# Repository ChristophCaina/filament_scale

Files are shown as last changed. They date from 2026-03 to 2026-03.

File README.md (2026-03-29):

# ⚖ ESPHome Filament Spool Scale & Winder

> 🇩🇪 [Deutsche Version weiter unten](#-esphome-filament-waage---wickler)

---

This project is an intelligent filament scale based on an ESP32. It offers precise weight measurement for 3D printing spools, an integrated spool database, and control for an optional winder add-on.  
The Primary goal of this project was also, to re-use some Hardware of an old Ender3 Printer, which is no longer in use.  
If you don't have the required parts remaining, consider to buy some cheap replacement parts online.

## ✨ Features

* **Precise Measurement:** Integration of a load cell (via `hx711` package) for real-time weight monitoring.
* **Smart UI:** Menu-driven display (via `st7920` package) with pagination.
<!-- * **Winder Mode:** Automatic detection of a stepper add-on for filament winding or unloading. -->
<!-- * **Potentiometer Control:** Stepless speed control of the stepper motor via analog potentiometer. -->
* **Modular Design:** Thanks to ESPHome "Packages," the logic is strictly separated from the hardware configuration.
* **Spoolman Integration:** Automatic sync of spool weight and status with your [Spoolman](https://github.com/Donkie/Spoolman) instance.
* **FilaMan Integration:** Compatible with [FilaMan](https://docu.filaman.app/) — a web-based open-source filament management system. Measured spool weights can be pushed to FilaMan for inventory tracking, fill-level monitoring, and printer integration (OctoPrint, Klipper/Moonraker).

---

## 🛠 Hardware & Pinout

Configuration is handled via `substitutions` in the local YAML file. The following pins are assigned by default:

| Component | Pin | Description |
| :--- | :--- | :--- |
| **Status LED** | GPIO02 | System status indicator |
| **Display (SPI)** | GPIO18 (CLK), GPIO23 (MOSI), GPIO17 (CS) | ST7920 128x64 LCD (`st7920` package) |
| **Rotary Encoder** | GPIO32 (A), GPIO33 (B), GPIO19 (BTN) | Navigation & Selection |
| **Buzzer** | GPIO16 | Acoustic feedback |
| **Load Cell (Scale)** | GPIO21 (DT), GPIO22 (SCK) | HX711 interface (`hx711` package) |
| **I2C Interface** | GPIO13 (SDA), GPIO14 (SCL) | Extensions(*) |
<!-- | **Stepper Motor** | GPIO25 (STEP), GPIO26 (DIR) | Winder drive | -->
<!-- | **Filament Sensor** | GPIO27 | Runout detection |-->
<!-- | **Speed** | GPIO34 (Analog) | Potentiometer (0 – 3.3V) | -->
<!-- | **Add-on Detection** | GPIO05 (Inp. Pullup) | Detects plugged-in winder module | -->

> **Note:** It is planned to add some extensions as an optional addon to this scale in the future, like a Spool-Rewinder and addon-detection. These will be added and documented once the hardware-design is finalized
---

## 🚀 Installation & Setup
this section isn't ready yet and will be adjusted over time.

<!-- To use this project on your hardware, follow these steps:

1. Create a **new device** in your ESPHome dashboard.
2. Copy the content of the [example_config.yaml](example_config.yaml) file from this repository.
3. Replace the content of your local configuration in the ESPHome dashboard with the copied text.
4. **Customization:**
   * Enter your WiFi credentials (`ssid` & `password`).
   * API and OTA keys are usually generated automatically by ESPHome when creating the device – ensure these are kept or regenerated.
   * Check the `substitutions` section to ensure the pinout matches your hardware.
5. **Compile & Install:** Click "Install" (USB or OTA).
6. **First Start:** After booting, zero the scale once via the menu item `1. Tare`.

### Spoolman Configuration

To configure Spoolman, set the substitution in the `example_config.yaml` to your Spoolman instance:

```yaml
spoolman_ip: "192.168.0.1:7912"
```

### FilaMan Configuration

[FilaMan](https://docu.filaman.app/) is a web-based open-source application for managing your filament inventory. It supports fill-level monitoring, manufacturer & filament tracking, storage locations, and printer integrations (OctoPrint, Klipper/Moonraker).

To connect this scale to FilaMan, set the corresponding substitution in the `example_config.yaml`:

```yaml
filaman_ip: "192.168.0.1:8083"
```

FilaMan can also be run as a **Home Assistant Add-on** — see [ha-filaman-system](https://github.com/netscout2001/ha-filaman-system).
-->

## Documentation:
* [Concept](docs/concept.md)
* [Hardware](docs/hardware.md)
* [Calibration](docs/calibration.md)
* [API Documentation](docs/api.md)

<!--
---
## 🌱 Supported Filament Suppliers

### Recycling Fabrik
Recycled filament from collected 3D printing waste.
Compatible with FilaMan NFC tags (coming soon).

<!-- [Shop ↗](https://recyclingfabrik.com) | [Collab Program ↗](https://recyclingfabrik.com/pages/collab)

> ℹ️ Affiliate links help support this project at no extra cost to you.
-->
---
 
## 📄 License
 
This project uses different licenses for different components:
 
| Component | License |
| :--- | :--- |
| **Firmware & Software** (YAML, Scripts, Workflows) | [MIT License](LICENSE) |
| **Hardware** (3D Print Files, PCB Layouts, Schematics) | [CC BY-NC-SA 4.0](LICENSE-HARDWARE) |
| **Documentation** | [CC BY-SA 4.0](https://creativecommons.org/licenses/by-sa/4.0/) |
 
### MIT License (Software)
The firmware and all software components are free to use, modify and distribute — including for commercial purposes — as long as the copyright notice is retained.
 
### CC BY-NC-SA 4.0 (Hardware)
Hardware design files (3D prints, PCB layouts) may be freely used, shared and adapted for **non-commercial purposes**, as long as appropriate credit is given and derivatives are shared under the same license.
 
> ℹ️ Affiliate links in the documentation do not constitute commercial use of the hardware designs.
 
---

# ⚖ ESPHome Filament-Waage & -Wickler

Dieses Projekt ist eine intelligente Filamentwaage auf Basis eines ESP32. Es bietet präzise Gewichtsmessung für 3D-Druck-Spulen, eine integrierte Spulendatenbank und die Steuerung eines optionalen Wickler-Add-ons. 
Ein Ziel für dieses Projekt war zudem die Verwertung einiger Bauteile eines alten, ausgedienten Ender3 Druckers.  
Solltest du nicht über die Notwendige Hardware verfügen, kannst du diese relativ günstig Online als Ersatzteile beziehen.

## ✨ Features

* **Präzise Messung:** Integration einer Wägezelle (über das `hx711`-Paket) zur Echtzeit-Gewichtsüberwachung.
* **Smartes UI:** Menügeführtes Display (über das `st7920`-Paket) mit Paginierung.
<!-- * **Wickler-Modus:** Automatische Erkennung eines Stepper-Add-ons zum Aufwickeln oder Entladen von Filament. -->
<!-- * **Poti-Steuerung:** Stufenlose Geschwindigkeitsregelung des Schrittmotors über ein analoges Potentiometer. -->
* **Modulares Design:** Dank ESPHome-„Packages" ist die Logik strikt von der Hardware-Konfiguration getrennt.
* **Spoolman-Anbindung:** Automatische Synchronisierung von Spulengewicht und -status mit deiner [Spoolman](https://github.com/Donkie/Spoolman)-Instanz.
* **FilaMan-Anbindung:** Kompatibel mit [FilaMan](https://docu.filaman.app/) – einem webbasierten Open-Source-System zur Filamentverwaltung. Gemessene Spulengewichte können an FilaMan übertragen werden: für Bestandsverwaltung, Füllstandsüberwachung und Druckerintegration (OctoPrint, Klipper/Moonraker).

---

## 🛠 Hardware & Pinbelegung

Die Konfiguration erfolgt über `substitutions` in der lokalen YAML-Datei. Folgende Pins sind standardmäßig belegt:

| Komponente | Pin | Beschreibung |
| :--- | :--- | :--- |
| **Status-LED** | GPIO02 | Systemstatusanzeige |
| **Display (SPI)** | GPIO18 (CLK), GPIO23 (MOSI), GPIO17 (CS) | ST7920 128x64 LCD (`st7920`-Paket) |
| **Drehgeber** | GPIO32 (A), GPIO33 (B), GPIO19 (BTN) | Navigation & Auswahl |
| **Summer** | GPIO16 | Akustisches Feedback |
| **Wägezelle** | GPIO21 (DT), GPIO22 (SCK) | HX711-Schnittstelle (`hx711`-Paket) |
| **I2C-Interface** | GPIO13 (SDA), GPIO14 (SCL) | Erweiterungen(*) |
<!-- | **Schrittmotor** | GPIO25 (STEP), GPIO26 (DIR) | Wicklerantrieb | -->
<!-- | **Filament-Sensor** | GPIO27 | Erkennung von Filamentmangel | -->
<!-- | **Geschwindigkeit** | GPIO34 (Analog) | Potentiometer (0 – 3,3 V) |-->
<!--| **Add-on-Erkennung** | GPIO05 (Inp. Pullup) | Erkennt angestecktes Wickler-Modul |-->

> **Notiz:** Es ist zu einem späteren Zeitpunkt geplant, Erweiterungen wie einen Spulen-Wickler und eine Addonerkennung als Optionale Features einzubinden. Diese werden hier dokumentiert, sobald die Hardware finalisiert wurde.
---

## 🚀 Installation & Einrichtung
Dieser Abschnitt ist aktuell noch nicht fertig gestellt und wird über die Zeit hin angepasst.
<!-- So verwendest du dieses Projekt auf deiner Hardware:

1. Erstelle ein **neues Gerät** in deinem ESPHome-Dashboard.
2. Kopiere den Inhalt der Datei [example_config.yaml](example_config.yaml) aus diesem Repository.
3. Ersetze den Inhalt deiner lokalen Konfiguration im ESPHome-Dashboard durch den kopierten Text.
4. **Anpassung:**
   * Trage deine WLAN-Zugangsdaten ein (`ssid` & `password`).
   * API- und OTA-Schlüssel werden von ESPHome beim Anlegen des Geräts normalerweise automatisch generiert – stelle sicher, dass diese übernommen oder neu generiert werden.
   * Überprüfe den Abschnitt `substitutions`, um sicherzustellen, dass die Pinbelegung deiner Hardware entspricht.
5. **Kompilieren & Installieren:** Klicke auf „Install" (USB oder OTA).
6. **Erster Start:** Starte nach dem Booten einmalig die Tarierung über den Menüpunkt `1. Tare`.

### Spoolman-Konfiguration

Um Spoolman zu konfigurieren, trage in der `example_config.yaml` die IP deiner Spoolman-Instanz ein:

```yaml
spoolman_ip: "192.168.0.1:7912"
```

### FilaMan-Konfiguration

[FilaMan](https://docu.filaman.app/) ist eine webbasierte Open-Source-Anwendung zur Verwaltung deines Filamentbestands. Sie unterstützt Füllstandsüberwachung, Hersteller- & Filamentverwaltung, Lagerorte sowie Druckerintegration (OctoPrint, Klipper/Moonraker).

Um diese Waage mit FilaMan zu verbinden, trage die entsprechende Substitution in der `example_config.yaml` ein:

```yaml
filaman_ip: "192.168.0.1:8083"
```

FilaMan kann auch als **Home Assistant Add-on** betrieben werden – siehe [ha-filaman-system](https://github.com/netscout2001/ha-filaman-system).
-->

## Dokumentation:
* [Konzept](docs/concept.md#-konzept--architektur)
* [Hardware](docs/hardware.md#-hardware-dokumentation)
* [Kalibrierung](docs/calibration.md#voraussetzungen)
* [API Dokumentation](docs/api.md#-api-dokumentation)

<!--
---
## 🌱 Unterstützte Filament Hersteller

### Recycling Fabrik
Nachhaltiges Filament aus 3D-Druck-Recycling.
Kompatibel mit FilaMan NFC-Tags (demnächst verfügbar).

[Shop ↗](https://recyclingfabrik.com) | [Collab Program ↗](https://recyclingfabrik.com/pages/collab)

> ℹ️ Affiliate links help support this project at no extra cost to you.
-->
---
## 📄 Lizenz

Dieses Projekt verwendet verschiedene Lizenzen für verschiedene Komponenten:
 
| Komponente | Lizenz |
| :--- | :--- |
| **Firmware & Software** (YAML, Scripts, Workflows) | [MIT Lizenz](LICENSE) |
| **Hardware** (3D-Druck-Dateien, PCB-Layouts, Schaltpläne) | [CC BY-NC-SA 4.0](LICENSE-HARDWARE) |
| **Dokumentation** | [CC BY-SA 4.0](https://creativecommons.org/licenses/by-sa/4.0/) |
 
### MIT Lizenz (Software)
Firmware und alle Software-Komponenten dürfen frei verwendet, verändert und weitergegeben werden — auch kommerziell — solange der Copyright-Hinweis erhalten bleibt.
 
### CC BY-NC-SA 4.0 (Hardware)
Hardware-Designdateien (3D-Drucke, PCB-Layouts) dürfen für **nicht-kommerzielle Zwecke** frei genutzt, geteilt und angepasst werden, sofern eine angemessene Namensnennung erfolgt und Ableitungen unter der gleichen Lizenz veröffentlicht werden.
 
> ℹ️ Affiliate-Links in der Dokumentation stellen keine kommerzielle Nutzung der Hardware-Designs dar.

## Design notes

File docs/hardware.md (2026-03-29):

# 🛠 Hardware Documentation

> 🇩🇪 [Deutsche Version weiter unten](#-hardware-dokumentation)

---

This document covers the hardware components used in this project, their wiring, and tips for sourcing and assembly.

---

## Bill of Materials (BOM)

| Component | Description | Qty | Price (approx.) | Link |
| :--- | :--- | :---: | --: | :-- |
| ESP32 Dev Board Mini | e.g. ESP32-WROOM-32 (38-pin) | 1 | - | - |
| **HX711 + Load Cell** | 24-bit ADC for load cells | 1 | 8,98 € | [Amazon ↗](https://amzn.to/4sH5u3X) |
| **ST7920 LCD** | Ender 3 display, 128×64, SPI | 1 | 17,99 € | [Amazon ↗](https://amzn.to/4bV3Lkr) |
| **PN532 NFC Module** | incl. NFC card + keyring chip + Dupont set | 1 | 6,50 € * | [Amazon ↗](https://amzn.to/4s40mFX) |
| PN5180 NFC Modul (v2) | NFC Reader / writer | 1 | - | - |
| **TMC2209 v2** | Stepper driver incl. heat sink, pre-soldered | 1 | 5,52 € * | [Amazon ↗](https://amzn.to/4sF8td9) |
| **NEMA17 Stepper** | 42 Ncm, for optional winder | 1 | 10,50 € | [Amazon ↗](https://amzn.to/48hPeOv) |
| Power Supply | 12 V | 1 | - | - |
<!-- | Potentiometer | 10 kΩ linear, for winder speed | 1 | -->
<!-- | Filament Runout Sensor*² | Mechanical switch or optical | 1 | -->

*\* Price per unit when buying the multi-pack*
 
**Estimated total cost (buying everything):**
| Configuration | Cost |
| :--- | ---: |
| Base (no stepper) | ~**38,94 €** |
| Full (with stepper) | ~**49,44 €** |
 
> ℹ️ The PN532 pack contains 2 modules — one extra for future use or a second scale. The TMC2209 pack contains 5 — extras are useful for other 3D printer projects.

> #### **Dimensions for the Load Cell**
> * **Overall Dimensions:** 80 mm x 12.7 mm x 12.7 mm
> * **Mounting Holes:** 4 x M4 or M5 (depending on model)
> * **Hole Spacing (Center to Center):**
>   * **Side A (Fixed Base):** 15 mm
>   * **Side B (Load End):** 15 mm
>   * **Distance between inner holes:** 40 mm

> #### ** *² Parts**
> All parts marked with *² are taken from an old Ender3 or Ender5.  
> If you don't have such a printer left for using the parts, you can get replacement parts pretty cheap on AliExpress for example.
---

## Pinout Overview

All pins are configurable via `substitutions` in `example_config.yaml`. The defaults are:

| Component | Pin | Notes |
| :--- | :--- | :--- |
| **Status LED** | GPIO02 | Built-in LED on most ESP32 boards |
| **Display CLK** | GPIO18 | SPI Clock |
| **Display MOSI** | GPIO23 | SPI Data |
| **Display CS** | GPIO17 | Chip Select |
| **Encoder A** | GPIO32 | Rotary channel A |
| **Encoder B** | GPIO33 | Rotary channel B |
| **Encoder BTN** | GPIO19 | Push-button (active low) |
| **Buzzer** | GPIO16 | PWM output |
| **Load Cell DT** | GPIO21 | HX711 Data (`waegezelle` package) |
| **Load Cell SCK** | GPIO22 | HX711 Clock (`waegezelle` package) |
| **I2C SDA** | GPIO13 | For optional extensions |
| **I2C SCL** | GPIO14 | For optional extensions |
| **Stepper STEP** | GPIO25 | Winder step pulse |
| **Stepper DIR** | GPIO26 | Winder direction |
| **Filament Sensor** | GPIO27 | Runout detection (active low) |
| **Speed (Poti)** | GPIO34 | Analog input (0–3.3 V), input-only pin |
| **Add-on Detection** | GPIO05 | Input with internal pull-up |

> ⚠️ GPIO34–GPIO39 on ESP32 are **input-only** and do not support internal pull-up/pull-down resistors. Use an external 10 kΩ pull-up if needed.

---

## Wiring Diagrams

### Load Cell → HX711 → ESP32

```
Load Cell         HX711          ESP32
─────────         ─────          ─────
RED   (E+)   ──►  E+
BLK   (E-)   ──►  E-
WHT   (A-)   ──►  A-
GRN   (A+)   ──►  A+
                  VCC ──────────►  3.3 V
                  GND ──────────►  GND
                  DT  ──────────►  GPIO21
                  SCK ──────────►  GPIO22
```

> ℹ️ Load cell wire colors may vary by manufacturer. Check the datasheet for your specific cell.

### ST7920 Display → ESP32 (SPI Mode) (from an old Ender3 or Ender5)

```
ST7920            ESP32
──────            ─────
VCC  ──────────►  5 V (or 3.3 V, check your module)
GND  ──────────►  GND
RS   ──────────►  GPIO17 (CS)
RW   ──────────►  GPIO23 (MOSI)
E    ──────────►  GPIO18 (CLK)
PSB  ──────────►  GND    (forces SPI mode)
RST  ──────────►  3.3 V  (or a free GPIO for software reset)
BLA  ──────────►  3.3 V  (backlight anode)
BLK  ──────────►  GND    (backlight cathode)
```

### Stepper Motor → Driver → ESP32

Both **A4988** and **TMC2209** (recommended) are supported. The STEP/DIR interface is identical for both — no firmware changes needed.

| Driver | Pros | Cons |
| :--- | :--- | :--- |
| **TMC2209** *(recommended)* | Very quiet (StealthChop), thermal protection, overcurrent protection | ~3–5€ |
| **A4988** | Cheap, widely available | Loud, minimal protection |

```
ESP32             Stepper-Driver          NEMA17
─────             ─────                   ──────
GPIO25 ────────►  STEP
GPIO26 ────────►  DIR
3.3 V  ────────►  VDD (logic)
GND    ────────►  GND (logic)
                  VMOT         ◄────      12 V PSU (+)
                  GND          ◄────      12 V PSU (-)
                  1A/1B        ────►      Coil A
                  2A/2B        ────►      Coil B
```

 ⚠️ Always set the current limit on the driver before connecting the stepper motor. For TMC2209, adjust the Vref potentiometer. For A4988, use a multimeter to set Vref according to your motor's rated current.
---

## Power Supply

This project uses a **single 12 V input** for all components. A step-down module converts 12 V to 5 V for the ESP32, display, and sensors. The ESP32 regulates 5 V down to 3.3 V internally.

> ⚠️ The Ender 3 display cannot be powered from the ESP32's USB port — it requires a dedicated 5 V supply with sufficient current. Always use the 12 V input with a step-down module.

```
12V PSU (Barrel Jack 5.5/2.1mm)
    ├── Step-Down (12V → 5V) ──► ESP32 VIN
    │                        ──► ST7920 Display VCC
    │                        ──► HX711 VCC
    │                        ──► PN532 NFC VCC
    │                        ──► Rotary Encoder VCC
    │                        ──► Buzzer
    │   (ESP32 regulates 5V → 3.3V internally)
    └── Direct 12V ──► Stepper Driver VMOT (Winder Add-on only)
```

| Rail | Consumers | Source |
| :--- | :--- | :--- |
| **12 V** | Stepper motor (optional) | 12 V PSU via barrel jack |
| **5 V** | ESP32 (VIN), Display, HX711, PN532, Encoder, Buzzer | Step-down module (e.g. MP1584) |
| **3.3 V** | ESP32 internals, sensors | ESP32 on-board regulator |

### Recommended Step-Down Module

Any adjustable step-down module works. Common options:

| Module | Input | Output | Notes |
| :--- | :--- | :--- | :--- |
| **MP1584** | 4.5–28 V | 0.8–20 V adj. | Compact, ~2€, 3A |
| **LM2596** | 4–40 V | 1.5–37 V adj. | Widely available, ~1€ |
| **XL4016** | 4–40 V | 1.25–36 V adj. | Higher current, ~2€ |

Set the output to **5.0 V** before connecting any components.
---

## Notes on the Optional Winder Add-on

The winder module connects via a dedicated connector. Its presence is detected via **GPIO05** (pulled high internally; grounded by the add-on connector). When not connected, all winder-related menu items are hidden automatically.

If you are building the winder module, ensure the connector shorts GPIO05 to GND when plugged in.

---

## Connectors & Assembly Options

This project is designed to be built in stages — from a quick breadboard prototype to a finished PCB. The connector choices reflect standard maker inventory.

### Prototyping (Breadboard)

For initial testing, use **Dupont jumper wires** (2.54mm) directly on the breadboard. All components connect via standard 2.54mm headers which are breadboard-compatible.

### Connectors for Permanent Assembly

All connectors are chosen to be compatible with **standard 2.54mm pitch perfboard/stripboard** (the most common prototype PCB kit format).

| Connection | Connector Type | Pitch | Pins | Notes |
| :--- | :--- | :--- | :---: | :--- |
| **Load Cell → HX711** | JST XH | 2.54mm | 4 | Red, Black, White, Green |
| **HX711 → ESP32** | Dupont / Pin Header | 2.54mm | 4 | DT, SCK, VCC, GND |
| **Display (ST7920)** | Dupont / Pin Header | 2.54mm | 10 | EXP1/EXP2 compatible |
| **Rotary Encoder** | Dupont / Pin Header | 2.54mm | 5 | CLK, DT, SW, VCC, GND |
| **Buzzer** | Dupont / Pin Header | 2.54mm | 2 | + / GND |
| **NFC (PN532)** | Dupont / Pin Header | 2.54mm | 4 | SDA, SCL, VCC, GND |
| **Stepper Driver** | Dupont / Pin Header | 2.54mm | 4 | STEP, DIR, VDD, GND |
| **12V Power Input** | Barrel Jack (THT) | — | — | 5.5mm/2.1mm, standard PSU plug |
| **Motor Power** | Screw Terminal | 5.08mm | 2 | VMOT / GND to stepper driver |

> ℹ️ **JST XH (2.54mm)** is the recommended connector for load cell and sensor connections — it fits standard perfboard and prevents accidental disconnection. Most maker supply stores carry JST XH pre-crimped cables.

> ℹ️ **Barrel Jack (5.5/2.1mm THT)** for 12V input is universally available and compatible with standard power supplies used for 3D printers.

### Ender 3 Display Connector

The Ender 3 / Ender 5 display uses two **10-pin Dupont connectors (2×5, 2.54mm pitch)** labeled EXP1 and EXP2. Standard Dupont housings and pins are used — no special cable required.

```
EXP1 / EXP2 Pinout (2×5, 2.54mm)
┌─────────────────────┐
│ 1  2  3  4  5       │
│ 6  7  8  9  10      │
└─────────────────────┘
Pin 1 = top-left (marked with triangle on PCB)
```

### Perfboard Compatibility

All connectors use **2.54mm pitch** to match the standard hole spacing of prototype PCB kits (e.g. 2×8cm, 3×7cm, 5×7cm boards). No special tools required beyond a soldering iron.

---
---

# 🛠 Hardware-Dokumentation

Dieses Dokument beschreibt die verwendeten Hardware-Komponenten, ihre Verdrahtung sowie Tipps zur Beschaffung und zum Aufbau.

---

## Stückliste (BOM)

| Komponente | Beschreibung | Menge | Preis (ca.) | Link |
| :--- | :--- | :---: | --: | :-- |
| ESP32 Dev Board Mini | e.g. ESP32-WROOM-32 (38-pin) | 1 | - | - |
| **HX711 + 5 kg Wägezelle** | 24-bit ADC for Wägezellen | 1 | 8,98 € | [Amazon ↗](https://amzn.to/4sH5u3X) |
| **ST7920 LCD** | Ender 3 display, 128×64, SPI | 1 | 17,99 € | [Amazon ↗](https://amzn.to/4bV3Lkr) |
| **PN532 NFC Modul** (v1) | inkl. NFC Karte + Schlüsselanhänger Chip + Dupont set | 1 | 6,50 € * | [Amazon ↗](https://amzn.to/4s40mFX) |
| PN5180 NFC Modul (v2) | NFC Leser / schreiber | 1 | - | - |
| **TMC2209 v2** | Stepper Treiber inkl. heat sink, Vorgelötet | 1 | 5,52 € * | [Amazon ↗](https://amzn.to/4sF8td9) |
| **NEMA17 Stepper Motor** | 42 Ncm, für Optionalen Winder | 1 | 10,50 € | [Amazon ↗](https://amzn.to/48hPeOv) |
| Netzteil | 12 V | 1 | - | - |
<!-- | Potentiometer | 10 kΩ linear, for winder speed | 1 | -->
<!-- | Filament Runout Sensor*² | Mechanical switch or optical | 1 | -->

*\* Price per unit when buying the multi-pack*
 
**Estimated total cost (buying everything):**
| Configuration | Cost |
| :--- | ---: |
| Base (no stepper) | ~**38,94 €** |
| Full (with stepper) | ~**49,44 €** |
 
> ℹ️ The PN532 pack contains 2 modules — one extra for future use or a second scale. The TMC2209 pack contains 5 — extras are useful for other 3D printer projects.

> #### **Abmessungen für die Wägezelle**
> * **Gesamtmaße:** 80 mm x 12,7 mm x 12,7 mm
> * **Bohrungen:** 4 x M4 oder M5 (je nach Modell)
> * **Lochabstände (Mitte zu Mitte):**
>   * **Seite A (Befestigung):** 15 mm
>   * **Seite B (Lastaufnahme):** 15 mm
>   * **Abstand zwischen den inneren Löchern:** 40 mm

> #### ** *² Teile**
> Alle mit *² gekennzeichneten Komponenten stammen von einem alten Ender3 oder Ender5.
> Sollte kein alter Drucker zum Ausschlachten verfügbar sein, können diese Teile günstig als Ersatzteile bei z.B. AliExpress bezogen werden.
---

## Pinbelegung (Übersicht)

Alle Pins sind über `substitutions` in der `example_config.yaml` konfigurierbar. Standardbelegung:

| Komponente | Pin | Hinweise |
| :--- | :--- | :--- |
| **Status-LED** | GPIO02 | Eingebaute LED auf den meisten ESP32-Boards |
| **Display CLK** | GPIO18 | SPI-Takt |
| **Display MOSI** | GPIO23 | SPI-Daten |
| **Display CS** | GPIO17 | Chip Select |
| **Encoder A** | GPIO32 | Drehgeber Kanal A |
| **Encoder B** | GPIO33 | Drehgeber Kanal B |
| **Encoder BTN** | GPIO19 | Drucktaste (aktiv-Low) |
| **Summer** | GPIO16 | PWM-Ausgang |
| **Wägezelle DT** | GPIO21 | HX711 Daten (`waegezelle`-Paket) |
| **Wägezelle SCK** | GPIO22 | HX711 Takt (`waegezelle`-Paket) |
| **I2C SDA** | GPIO13 | Für optionale Erweiterungen |
| **I2C SCL** | GPIO14 | Für optionale Erweiterungen |
| **Schrittmotor STEP** | GPIO25 | Wickler-Schrittimpuls |
| **Schrittmotor DIR** | GPIO26 | Wickler-Richtung |
| **Filament-Sensor** | GPIO27 | Runout-Erkennung (aktiv-Low) |
| **Geschwindigkeit (Poti)** | GPIO34 | Analogeingang (0–3,3 V), nur Eingang |
| **Add-on-Erkennung** | GPIO05 | Eingang mit internem Pull-up |

> ⚠️ GPIO34–GPIO39 am ESP32 sind **nur als Eingang** nutzbar und unterstützen keine internen Pull-up/Pull-down-Widerstände. Bei Bedarf externen 10-kΩ-Pull-up verwenden.

---

## Verdrahtungspläne

### Wägezelle → HX711 → ESP32

```
Wägezelle         HX711          ESP32
─────────         ─────          ─────
ROT     (E+)   ──►  E+
SCHWARZ (E-)   ──►  E-
WEISS   (A-)   ──►  A-
GRÜN    (A+)   ──►  A+
                    VCC ──────────►  3,3 V
                    GND ──────────►  GND
                    DT  ──────────►  GPIO21
                    SCK ──────────►  GPIO22
```

> ℹ️ Die Kabelfarben der Wägezelle können je nach Hersteller abweichen. Das Datenblatt der jeweiligen Zelle prüfen.

### ST7920 Display → ESP32 (SPI-Modus) (von einem alten Ender3 or Ender5)

```
ST7920            ESP32
──────            ─────
VCC  ──────────►  5 V (oder 3,3 V – Modul-Datenblatt prüfen)
GND  ──────────►  GND
RS   ──────────►  GPIO17 (CS)
RW   ──────────►  GPIO23 (MOSI)
E    ──────────►  GPIO18 (CLK)
PSB  ──────────►  GND    (erzwingt SPI-Modus)
RST  ──────────►  3,3 V  (oder freier GPIO für Software-Reset)
BLA  ──────────►  3,3 V  (Hintergrundbeleuchtung Anode)
BLK  ──────────►  GND    (Hintergrundbeleuchtung Kathode)
```

### Schrittmotor → Treiber → ESP32

Sowohl **A4988** als auch **TMC2209** (empfohlen) werden unterstützt. Das STEP/DIR-Interface ist bei beiden identisch — keine Firmware-Änderungen nötig.

| Treiber | Vorteile | Nachteile |
| :--- | :--- | :--- |
| **TMC2209** *(empfohlen)* | Sehr leise (StealthChop), Überhitzungsschutz, Überstromschutz | ~3–5€ |
| **A4988** | Günstig, überall verfügbar | Laut, minimaler Schutz |

```
ESP32             Stepper-Treiber          NEMA17
─────             ─────                    ──────
GPIO25 ────────►  STEP
GPIO26 ────────►  DIR
3,3 V  ────────►  VDD (Logik)
GND    ────────►  GND (Logik)
                  VMOT       ◄────        12-V-Netzteil (+)
                  GND        ◄────        12-V-Netzteil (-)
                  1A/1B      ────►        Spule A
                  2A/2B      ────►        Spule B
```

> ⚠️ Den Strombegrenzungspoti vor dem Anschluss des Schrittmotors einstellen. Beim TMC2209 den Vref-Poti entsprechend dem Nennstrom des Motors einstellen. Beim A4988 den Vref-Wert per Multimeter messen.

---

## Stromversorgung

Dieses Projekt verwendet einen **einzigen 12-V-Eingang** für alle Komponenten. Ein Stepdown-Modul wandelt 12 V auf 5 V für ESP32, Display und Sensoren um. Der ESP32 regelt 5 V intern auf 3,3 V herunter.

> ⚠️ Das Ender-3-Display kann **nicht** über den USB-Port des ESP32 betrieben werden — es benötigt eine dedizierte 5-V-Versorgung mit ausreichend Strom. Immer den 12-V-Eingang mit Stepdown-Modul verwenden.

```
12V Netzteil (Hohlstecker 5,5/2,1mm)
    ├── Stepdown (12V → 5V) ──► ESP32 VIN
    │                       ──► ST7920 Display VCC
    │                       ──► HX711 VCC
    │                       ──► PN532 NFC VCC
    │                       ──► Drehgeber VCC
    │                       ──► Summer
    │   (ESP32 regelt intern 5V → 3,3V)
    └── Direkt 12V ──► Schrittmotortreiber VMOT (nur Wickler-Add-on)
```

| Schiene | Verbraucher | Quelle |
| :--- | :--- | :--- |
| **12 V** | Schrittmotor (optional) | 12-V-Netzteil via Hohlstecker |
| **5 V** | ESP32 (VIN), Display, HX711, PN532, Encoder, Summer | Stepdown-Modul (z.B. MP1584) |
| **3,3 V** | ESP32-Interna, Sensoren | ESP32 On-Board-Regler |

### Empfohlene Stepdown-Module

Jedes einstellbare Stepdown-Modul ist geeignet. Gängige Optionen:

| Modul | Eingang | Ausgang | Hinweise |
| :--- | :--- | :--- | :--- |
| **MP1584** | 4,5–28 V | 0,8–20 V einstellbar | Kompakt, ~2€, 3A |
| **LM2596** | 4–40 V | 1,5–37 V einstellbar | Weit verbreitet, ~1€ |
| **XL4016** | 4–40 V | 1,25–36 V einstellbar | Höherer Strom, ~2€ |

Ausgang auf **5,0 V** einstellen **bevor** Komponenten angeschlossen werden.
---

## Hinweise zum optionalen Wickler-Add-on

Das Wicklermodul wird über einen dedizierten Stecker verbunden. Seine Anwesenheit wird über **GPIO05** erkannt (intern High gezogen; durch den Add-on-Stecker auf GND gelegt). Ist kein Wickler angesteckt, werden alle Wickler-Menüpunkte automatisch ausgeblendet.

Beim Bau des Wicklermoduls sicherstellen, dass der Stecker GPIO05 im eingesteckten Zustand mit GND verbindet.

---
 
## Steckverbinder & Aufbauoptionen
 
Dieses Projekt ist so konzipiert, dass es stufenweise aufgebaut werden kann — vom schnellen Breadboard-Prototypen bis zur fertigen Platine. Die Steckverbinder entsprechen dem Standard-Maker-Inventar.
 
### Prototyping (Breadboard)
 
Für erste Tests können **Dupont Jumper-Kabel (2.54mm)** direkt auf dem Breadboard verwendet werden. Alle Komponenten nutzen Standard-2.54mm-Stiftleisten, die breadboard-kompatibel sind.
 
### Steckverbinder für den permanenten Aufbau
 
Alle Steckverbinder sind kompatibel mit **Standard-2.54mm-Lochrasterplatinen** (das gängigste Format in Prototypen-PCB-Kits).
 
| Verbindung | Steckverbinder | Raster | Pins | Hinweise |
| :--- | :--- | :--- | :---: | :--- |
| **Wägezelle → HX711** | JST XH | 2.54mm | 4 | Rot, Schwarz, Weiß, Grün |
| **HX711 → ESP32** | Dupont / Stiftleiste | 2.54mm | 4 | DT, SCK, VCC, GND |
| **Display (ST7920)** | Dupont / Stiftleiste | 2.54mm | 10 | EXP1/EXP2 kompatibel |
| **Drehgeber (Encoder)** | Dupont / Stiftleiste | 2.54mm | 5 | CLK, DT, SW, VCC, GND |
| **Summer (Buzzer)** | Dupont / Stiftleiste | 2.54mm | 2 | + / GND |
| **NFC (PN532)** | Dupont / Stiftleiste | 2.54mm | 4 | SDA, SCL, VCC, GND |
| **Schrittmotor-Treiber** | Dupont / Stiftleiste | 2.54mm | 4 | STEP, DIR, VDD, GND |
| **12V Eingang** | Hohlstecker-Buchse (THT) | — | — | 5.5mm/2.1mm, Standard-Netzteilstecker |
| **Motorstrom** | Schraubklemme | 5.08mm | 2 | VMOT / GND zum Schrittmotortreiber |
 
> ℹ️ **JST XH (2.54mm)** wird für Wägezellen- und Sensoranschlüsse empfohlen — passt auf Lochrasterplatinen und verhindert versehentliches Trennen. In den meisten Maker-Shops gibt es JST XH als vorkonfektionierte Kabel.
 
> ℹ️ **Hohlstecker-Buchse (5.5/2.1mm THT)** für den 12V-Eingang ist universell verfügbar und kompatibel mit Standard-Netzteilen für 3D-Drucker.
 
### Ender 3 Display-Stecker
 
Das Ender 3 / Ender 5 Display verwendet zwei **10-polige Dupont-Stecker (2×5, 2.54mm Raster)**, beschriftet als EXP1 und EXP2. Standard-Dupont-Gehäuse und Pins werden verwendet — kein Spezialkabel erforderlich.
 
```
EXP1 / EXP2 Belegung (2×5, 2.54mm)
┌─────────────────────┐
│ 1  2  3  4  5       │
│ 6  7  8  9  10      │
└─────────────────────┘
Pin 1 = oben links (auf der Platine mit Dreieck markiert)
```
 
### Lochraster-Kompatibilität
 
Alle Steckverbinder verwenden **2.54mm Raster** passend zum Standard-Lochabstand der gängigen Prototypen-PCB-Kits (z.B. 2×8cm, 3×7cm, 5×7cm Platinen). Kein Spezialwerkzeug erforderlich — nur ein Lötkolben.

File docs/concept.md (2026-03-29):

# 🧠 Concept & Architecture

> 🇩🇪 [Deutsche Version weiter unten](#-konzept--architektur)

---

## Vision

The Filament Scale is more than just a weighing device — it is a **universal bridge between all major filament management ecosystems**.

While most solutions are locked to a single ecosystem, this project connects them all:

| Ecosystem | Protocol | Support |
| :--- | :--- | :--- |
| **Home Assistant** | ESPHome Native API | ✅ Full integration |
| **Spoolman** | REST API (PATCH) | ✅ Weight sync |
| **FilaMan** | Spoolman-compatible API | ✅ Weight sync, Tag-Creation / Update |
| **Mifare / NTAG Tags** | ISO 14443 via PN532 | ✅ v1 |
| **OpenPrintTag (Prusa)** | ISO 15693 via PN5180 | 🔲 v2 |

> 💡 FilaMan currently uses a PN532 reader and cannot read OpenPrintTag (ISO 15693) tags. This scale — with a PN5180 — can act as a bridge: reading OpenPrintTag spools and syncing their data to FilaMan or Spoolman.

---

## Architecture / Package Structure

```
user-config.yaml             ← Local device file (user-owned, never overwritten)
│
├── substitutions:           ← Hardware-specific values (pins, IPs)
│   └── (empty = HA entity has priority)
│   └── (set = substitution overrides on boot)
│
├── api: encryption: key:    ← Generated by ESPHome on Take Control
├── wifi:                    ← User's WiFi credentials
├── ota:                     ← ESPHome OTA platform
│
└── packages:
    └── filament_scale:      ← github://...filament-scale.yaml@main
                                (contains all functionality)
```

```
filament-scale.yaml          ← Core package on GitHub (all functionality)
│
└── packages:
    ├── base.yaml            ← Status LED, Buzzer, Beep scripts
    ├── scale.yaml           ← HX711: calibration, tare, weight, filament %
    ├── display.yaml         ← ST7920: menu rendering, pagination
    ├── controls.yaml        ← Rotary encoder: navigation input
    ├── sync.yaml            ← Unified Spoolman/FilaMan sync
    ├── stepper.yaml         ← Stepper motor control
    ├── winder.yaml          ← Winder add-on detection
    └── nfc.yaml             ← PN532 NFC tag reading/writing
```

```
factory.yaml                 ← Web Installer only (initial flash)
│                               Contains: improv_serial, captive_portal,
│                               api (no key), ota, dashboard_import
└── packages:
    └── filament_scale:      ← same filament-scale.yaml
```

---

## Key Design Decisions

### Two-tier architecture: factory.yaml + user-config.yaml

The most important architectural decision: **credentials and API keys never live on GitHub**.

- `factory.yaml` — flashed once via Web Installer, contains no credentials
- `user-config.yaml` — generated by ESPHome "Take Control", contains API key + WiFi
- OTA updates via ESPHome Dashboard recompile `user-config.yaml` → **API key survives updates**
- OTA updates via Home Assistant flash `factory.yaml` binary → for users without ESPHome

### Normal User vs. Power User

All configurable values (calibration factor, Spoolman/FilaMan IP) follow a priority system:

```
Substitution empty  →  HA entity has priority  (Normal User)
Substitution set    →  Substitution overrides on boot  (Power User)
```

Normal Users configure everything via Home Assistant UI. Power Users set substitutions in their local YAML — these persist across OTA updates.

### Why ESPHome?

- No custom firmware needed — everything is YAML
- Native Home Assistant integration
- OTA updates without cloud dependency
- Web Installer for first-time setup (no drivers, no software)
- Active community and long-term support

### Why ST7920 + Rotary Encoder?

Simple, reliable, low-power. Wide availability as Ender 3/5 spare part — many makers already have one. No touch calibration complexity near metal parts.

### Why HX711?

De facto standard for DIY load cell interfaces. 24-bit resolution, built-in amplification, excellent ESPHome support. Calibration is done via Home Assistant number entity — no reflash needed.

### Winder as Optional Add-on

Auto-detected via GPIO05 (pulled high, grounded when add-on connected). Base device works as a standalone scale without winder attached. No separate firmware variant needed.

---

## Boot Flow

```
Boot
 │
 ├─► Connect WiFi
 │    ├─► Connected → register with Home Assistant
 │    └─► Failed → start Fallback AP + Captive Portal
 │
 ├─► on_boot: apply substitutions (if set)
 │    ├─► scale_calibration_factor → calibration_factor entity
 │    ├─► spoolman_ip → text_spoolman_ip entity
 │    └─► filaman_ip → text_filaman_ip entity
 │
 ├─► script_detect_backend
 │    ├─► FilaMan IP set → use FilaMan API
 │    ├─► Spoolman IP set → use Spoolman API
 │    └─► Neither set → sync disabled
 │
 ├─► Check Add-on GPIO (GPIO05)
 │    ├─► Winder detected → enable winder menu items
 │    └─► No winder → hide winder menu items
 │
 └─► Main Loop
      ├─► Read weight (scale.yaml) → update HA sensors
      ├─► NFC tag detected? → read ID → set spool_id → sync
      ├─► Encoder input → navigate menu
      └─► Winder active? → read potentiometer → set stepper speed
```

---

## Roadmap

| Status | Feature |
| :--- | :--- |
| ✅ | Web Installer (ESP Web Tools + Improv WiFi) |
| ✅ | ESPHome Take Control flow |
| ✅ | ESPHome Webserver |
| 🔲 | OTA Updates via Home Assistant |
| 🔲 | OTA Updates via ESPHome Dashboard (API key survives) |
| 🔲 | Spoolman integration (weight sync) |
| 🔲 | FilaMan integration (weight sync) |
| ✅ | Scale-Calibration via HA number entity (no reflash) |
| ✅ | Spoolman/FilaMan IP via HA text entity |
| 🔲 | Optional winder add-on with auto-detection |
| ✅ | PN532 NFC reader — Mifare/NTAG tag detection |
| 🔲 | ST7920 display menu system |
| 🔲 | NFC tag read → auto-set Spoolman spool ID |
| 🔲 | NFC tag write (write-back from Spoolman) |
| 🔲 | PN5180 support → OpenPrintTag (ISO 15693) |
| 🔲 | PCB design (perfboard compatible, THT) |
| 🔲 | 3D printable enclosure |
| 🔲 | devices.esphome.io listing |

---
---

# 🧠 Konzept & Architektur

---

## Vision

Die Filament-Waage ist mehr als ein Wiegegerät — sie ist eine **universelle Brücke zwischen allen wichtigen Filament-Management-Ökosystemen**.

Während die meisten Lösungen auf ein einzelnes Ökosystem beschränkt sind, verbindet dieses Projekt alle miteinander:

| Ökosystem | Protokoll | Unterstützung |
| :--- | :--- | :--- |
| **Home Assistant** | ESPHome Native API | ✅ Vollständige Integration |
| **Spoolman** | REST API (PATCH) | ✅ Gewichtssync |
| **FilaMan** | Spoolman-kompatibler API | ✅ Gewichtssync / Tag-Erstellung, Tag-Update |
| **Mifare / NTAG Tags** | ISO 14443 via PN532 | ✅ v1 |
| **OpenPrintTag (Prusa)** | ISO 15693 via PN5180 | 🔲 v2 |

> 💡 FilaMan nutzt aktuell einen PN532-Reader und kann keine OpenPrintTag-Tags (ISO 15693) lesen. Diese Waage kann — mit einem PN5180 — als Brücke fungieren: OpenPrintTag-Spulen lesen und die Daten an FilaMan oder Spoolman übertragen.

---

## Architektur / Package-Struktur

```
user-config.yaml             ← Lokale Gerätedatei (nutzereigen, wird nie überschrieben)
│
├── substitutions:           ← Hardwarespezifische Werte (Pins, IPs)
│   └── (leer = HA-Entity hat Priorität)
│   └── (gesetzt = Substitution überschreibt beim Boot)
│
├── api: encryption: key:    ← Von ESPHome bei "Take Control" generiert
├── wifi:                    ← WLAN-Zugangsdaten des Nutzers
├── ota:                     ← ESPHome OTA-Plattform
│
└── packages:
    └── filament_scale:      ← github://...filament-scale.yaml@main
                                (enthält die gesamte Funktionalität)
```

```
filament-scale.yaml          ← Core-Package auf GitHub (gesamte Funktionalität)
│
└── packages:
    ├── base.yaml            ← Status-LED, Summer, Beep-Scripts
    ├── scale.yaml           ← HX711: Kalibrierung, Tare, Gewicht, Filament-%
    ├── display.yaml         ← ST7920: Menü-Rendering, Paginierung
    ├── controls.yaml        ← Drehgeber: Navigationseingabe
    ├── sync.yaml            ← Einheitlicher Spoolman/FilaMan-Sync
    ├── stepper.yaml         ← Schrittmotorsteuerung
    ├── winder.yaml          ← Wickler-Add-on-Erkennung
    └── nfc.yaml             ← PN532 NFC-Tag lesen/schreiben
```

```
factory.yaml                 ← Nur für Web Installer (Erstinstallation)
│                               Enthält: improv_serial, captive_portal,
│                               api (kein Key), ota, dashboard_import
└── packages:
    └── filament_scale:      ← dieselbe filament-scale.yaml
```

---

## Wichtige Designentscheidungen

### Zweistufige Architektur: factory.yaml + user-config.yaml

Die wichtigste Architekturentscheidung: **Zugangsdaten und API-Keys leben nie auf GitHub**.

- `factory.yaml` — einmalig per Web Installer geflasht, enthält keine Zugangsdaten
- `user-config.yaml` — von ESPHome "Take Control" generiert, enthält API-Key + WLAN
- OTA-Updates via ESPHome Dashboard kompilieren `user-config.yaml` neu → **API-Key überlebt Updates**
- OTA-Updates via Home Assistant flashen `factory.yaml` Binary → für Nutzer ohne ESPHome

### Normal User vs. Power User

Alle konfigurierbaren Werte (Kalibrierungsfaktor, Spoolman/FilaMan-IP) folgen einem Prioritätssystem:

```
Substitution leer  →  HA-Entity hat Priorität  (Normal User)
Substitution gesetzt  →  Substitution überschreibt beim Boot  (Power User)
```

Normal User konfigurieren alles über die Home Assistant UI. Power User setzen Substitutions in ihrer lokalen YAML — diese bleiben über OTA-Updates hinweg erhalten.

### Warum ESPHome?

- Keine eigene Firmware nötig — alles ist YAML
- Native Home-Assistant-Integration
- OTA-Updates ohne Cloud-Abhängigkeit
- Web Installer für die Ersteinrichtung (keine Treiber, keine Software)
- Aktive Community und langfristiger Support

### Warum ST7920 + Drehgeber?

Einfach, zuverlässig, stromsparend. Weit verbreitet als Ender-3/5-Ersatzteil — viele Maker haben bereits eines. Keine Touch-Kalibrierungskomplexität in der Nähe von Metallteilen.

### Warum HX711?

De-facto-Standard für DIY-Wägezelleninterfaces. 24-Bit-Auflösung, eingebaute Verstärkung, exzellente ESPHome-Unterstützung. Die Kalibrierung erfolgt über eine Home-Assistant-Number-Entity — kein erneutes Flashen erforderlich.

### Wickler als optionales Add-on

Automatische Erkennung via GPIO05 (High-gezogen, bei angestecktem Add-on auf GND). Das Basisgerät funktioniert als eigenständige Waage ohne Wickler. Keine separate Firmware-Variante nötig.

---

## Startablauf

```
Start
 │
 ├─► WLAN verbinden
 │    ├─► Verbunden → bei Home Assistant registrieren
 │    └─► Fehlgeschlagen → Fallback-AP + Captive Portal starten
 │
 ├─► on_boot: Substitutions anwenden (falls gesetzt)
 │    ├─► scale_calibration_factor → calibration_factor Entity
 │    ├─► spoolman_ip → text_spoolman_ip Entity
 │    └─► filaman_ip → text_filaman_ip Entity
 │
 ├─► script_detect_backend
 │    ├─► FilaMan-IP gesetzt → FilaMan-API verwenden
 │    ├─► Spoolman-IP gesetzt → Spoolman-API verwenden
 │    └─► Keine gesetzt → Sync deaktiviert
 │
 ├─► Add-on-GPIO prüfen (GPIO05)
 │    ├─► Wickler erkannt → Wickler-Menüpunkte aktivieren
 │    └─► Kein Wickler → Wickler-Menüpunkte ausblenden
 │
 └─► Hauptschleife
      ├─► Gewicht lesen (scale.yaml) → HA-Sensoren aktualisieren
      ├─► NFC-Tag erkannt? → ID lesen → Spool-ID setzen → Sync
      ├─► Drehgeber-Eingabe → Menü navigieren
      └─► Wickler aktiv? → Potentiometer lesen → Schrittmotorgeschwindigkeit setzen
```

---

## Roadmap

| Status | Feature |
| :--- | :--- |
| ✅ | Web Installer (ESP Web Tools + Improv WiFi) |
| ✅ | ESPHome Take Control Flow |
| ✅ | ESPHome Webserver |
| 🔲 | OTA-Updates via Home Assistant |
| 🔲 | OTA-Updates via ESPHome Dashboard (API-Key bleibt erhalten) |
| 🔲 | Spoolman-Integration (Gewichtssync) |
| 🔲 | FilaMan-Integration (Gewichtssync) |
| ✅ | Waagen-Kalibrierung via HA Number Entity (kein Reflash) |
| ✅ | Spoolman/FilaMan-IP via HA Text Entity |
| 🔲 | Optionales Wickler-Add-on mit automatischer Erkennung |
| ✅ | PN532 NFC-Reader — Mifare/NTAG-Tag-Erkennung |
| 🔲 | ST7920 Display Menü-System |
| 🔲 | NFC-Tag lesen → Spoolman Spool-ID automatisch setzen |
| 🔲 | NFC-Tag schreiben (Write-Back von Spoolman) |
| 🔲 | PN5180-Unterstützung → OpenPrintTag (ISO 15693) |
| 🔲 | PCB-Design (Lochraster-kompatibel, THT) |
| 🔲 | 3D-Druck Gehäuse |
| 🔲 | devices.esphome.io Eintrag |

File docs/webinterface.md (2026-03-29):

# 📊 Web Interface

> 🇩🇪 [Deutsche Version weiter unten](#-web-interface-1)

---

The Filament Scale includes a built-in web interface accessible directly from any browser on your local network — no app, no Home Assistant required.

The interface is powered by **ESPHome Web Server v3** and supports both light and dark mode automatically based on your system preferences.

---

## Accessing the Interface

Open a browser and navigate to:

```
http://fila-scale.local
```

Or use the device's IP address directly:

```
http://192.168.x.x
```

> ℹ️ mDNS (`fila-scale.local`) requires a compatible operating system. Windows 10+, macOS, and Linux with Avahi all support this out of the box.

---

## Interface Overview

### Light Mode

Web Interface — Light Mode
*Web interface in light mode showing Sensor and Control section*

### Dark Mode

Web Interface — Dark Mode
*Web interface in dark mode showing Sensor and Control section*

---

## Sensor and Control

Sensor and Control Section

| Entity | Type | Description |
| :--- | :--- | :--- |
| **Filament Remaining** | Sensor | Remaining filament in % |
| **Weight** | Sensor | Current weight in grams |
| **Sync** | Button | Push current weight to Spoolman / FilaMan |
| **Winder Add-on** | Binary Sensor | Winder add-on detected at boot |
| **Winder Speed** | Sensor | Current winder motor speed in % |
| **Winder Toggle** | Button | Toggle winder motor on/off |

---

## Configuration

Configuration Section

| Entity | Type | Description |
| :--- | :--- | :--- |
| **Calibration Factor** | Number (Slider) | Scale calibration factor — see [Calibration Guide](calibration.md) |
| **Empty Spool Weight** | Number (Slider) | Weight of the empty spool in grams |
| **Total Filament Weight** | Number (Slider) | Total filament weight when full in grams |
| **Spoolman IP** | Text | IP address and port of your Spoolman instance |
| **FilaMan IP** | Text | IP address and port of your FilaMan instance |
| **Tare Scale** | Button | Zero the scale with an empty platform |
| **Firmware Update** | Update | Shows current firmware status and triggers OTA update |

> ℹ️ All configuration values are stored directly on the device and survive reboots. No reflash required.

---

## Diagnostic

| Entity | Type | Description |
| :--- | :--- | :--- |
| **Scale Raw** | Sensor | Raw HX711 value — used for calibration |

---

## OTA Update

The web interface also provides a manual OTA update option at the bottom of the page. You can select a local `.bin` file and flash it directly without Home Assistant or ESPHome Dashboard.

---

## Features

- ✅ No app or Home Assistant required
- ✅ Light and dark mode (follows system preference)
- ✅ Sliders for number entities (Calibration Factor, Spool Weights)
- ✅ Sensor history graphs (click any sensor to expand)
- ✅ Manual OTA update via file upload
- ✅ Live debug log

---
---

# 📊 Web-Interface

Das Filament Scale verfügt über ein eingebautes Web-Interface, das direkt über jeden Browser im lokalen Netzwerk erreichbar ist — ohne App, ohne Home Assistant.

Das Interface basiert auf dem **ESPHome Web Server v3** und unterstützt automatisch Light und Dark Mode basierend auf den Systemeinstellungen.

---

## Zugriff auf das Interface

Browser öffnen und navigieren zu:

```
http://fila-scale.local
```

Oder direkt über die IP-Adresse:

```
http://192.168.x.x
```

> ℹ️ mDNS (`fila-scale.local`) erfordert ein kompatibles Betriebssystem. Windows 10+, macOS und Linux mit Avahi unterstützen dies standardmäßig.

---

## Interface-Übersicht

### Light Mode

Web Interface — Light Mode
*Web-Interface im Light Mode mit Sensor- und Steuerbereich*

### Dark Mode

Web Interface — Dark Mode
*Web-Interface im Dark Mode mit Sensor- und Steuerbereich*

---

## Sensoren und Steuerung

Sensor and Control Section

| Entität | Typ | Beschreibung |
| :--- | :--- | :--- |
| **Filament Remaining** | Sensor | Verbleibendes Filament in % |
| **Weight** | Sensor | Aktuelles Gewicht in Gramm |
| **Sync** | Button | Aktuelles Gewicht an Spoolman / FilaMan senden |
| **Winder Add-on** | Binärsensor | Wickler-Erweiterung beim Boot erkannt |
| **Winder Speed** | Sensor | Aktuelle Wickler-Motorgeschwindigkeit in % |
| **Winder Toggle** | Button | Wicklermotor ein-/ausschalten |

---

## Konfiguration

Configuration Section

| Entität | Typ | Beschreibung |
| :--- | :--- | :--- |
| **Calibration Factor** | Number (Slider) | Kalibrierungsfaktor der Waage — siehe [Kalibrierungsanleitung](calibration.md) |
| **Empty Spool Weight** | Number (Slider) | Leergewicht der Spule in Gramm |
| **Total Filament Weight** | Number (Slider) | Gesamtfilamentgewicht bei voller Spule in Gramm |
| **Spoolman IP** | Text | IP-Adresse und Port der Spoolman-Instanz |
| **FilaMan IP** | Text | IP-Adresse und Port der FilaMan-Instanz |
| **Tare Scale** | Button | Waage mit leerer Plattform nullen |
| **Firmware Update** | Update | Zeigt Firmware-Status und löst OTA-Update aus |

> ℹ️ Alle Konfigurationswerte werden direkt auf dem Gerät gespeichert und überleben Neustarts. Kein erneutes Flashen erforderlich.

---

## Diagnose

| Entität | Typ | Beschreibung |
| :--- | :--- | :--- |
| **Scale Raw** | Sensor | Rohwert des HX711 — wird für die Kalibrierung verwendet |

---

## OTA Update

Das Web-Interface bietet am unteren Ende der Seite eine manuelle OTA-Update-Option. Eine lokale `.bin`-Datei kann direkt ausgewählt und geflasht werden — ohne Home Assistant oder ESPHome Dashboard.

---

## Features

- ✅ Keine App oder Home Assistant erforderlich
- ✅ Light und Dark Mode (folgt Systemeinstellung)
- ✅ Slider für Number-Entitäten (Kalibrierungsfaktor, Spulengewichte)
- ✅ Sensor-Verlaufsgraphen (Klick auf einen Sensor zum Aufklappen)
- ✅ Manuelles OTA-Update per Datei-Upload
- ✅ Live Debug-Log

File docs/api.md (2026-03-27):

# 🔌 API Documentation

> 🇩🇪 [Deutsche Version weiter unten](#-api-dokumentation)

---

This document describes all external interfaces of the ESPHome Filament Scale: the native ESPHome REST API, Home Assistant integration, and the unified sync logic for Spoolman and FilaMan.

---

## ESPHome REST API

ESPHome exposes a built-in REST API that allows reading sensor values and triggering actions without Home Assistant.

**Base URL:** `http://<device-ip>/`

### Sensor States

```http
GET /sensor/<sensor_id>
```

| Sensor ID | Description |
| :--- | :--- |
| `filament_weight` | Current net weight in grams |
| `filament_remaining_pct` | Calculated remaining filament in % |

**Example:**
```bash
curl http://192.168.0.50/sensor/filament_weight
```
```json
{ "id": "sensor-filament_weight", "value": 217.4, "state": "217.4 g" }
```

### Button Actions

```http
POST /button/<button_id>/press
```

| Button ID | Description |
| :--- | :--- |
| `tare_scale` | Zero/tare the scale |
| `sync` | Manually trigger sync to active backend |

**Example:**
```bash
curl -X POST http://192.168.0.50/button/sync/press
```

---

## Home Assistant Integration

The device integrates natively into Home Assistant via the **ESPHome integration** (API key required).

### Setup

1. In Home Assistant, go to **Settings → Devices & Services → Add Integration → ESPHome**.
2. Enter the device IP address.
3. Enter the API key from your `example_config.yaml`.

### Available Entities

| Entity | Type | Description |
| :--- | :--- | :--- |
| `sensor.filament_weight` | Sensor | Current net weight (g) |
| `sensor.filament_remaining_pct` | Sensor | Remaining filament (%) |
| `button.tare_scale` | Button | Tare the scale |
| `button.sync` | Button | Trigger sync to active backend |
| `switch.winder_enabled` | Switch | Enable/disable winder motor |
| `number.winder_speed` | Number | Winder speed (0–100%) |

### Example Automation

```yaml
automation:
  - alias: "Notify when filament running low"
    trigger:
      - platform: numeric_state
        entity_id: sensor.filament_remaining_pct
        below: 15
    action:
      - service: notify.mobile_app
        data:
          message: "⚠️ Filament below 15% – please reload spool!"
```

---

## Sync Logic — FilaMan & Spoolman

The scale uses a **single unified sync mechanism** (`sync.yaml`) that automatically selects the correct backend at boot. Both FilaMan and Spoolman share the same Spoolman-compatible REST API, so the HTTP call is identical — only the base URL differs.

### How FilaMan and Spoolman relate

FilaMan provides a **Spoolman API Plugin** that exposes a fully Spoolman-compatible REST API under `/spoolman/api/v1/`. External tools can use FilaMan as a drop-in replacement for Spoolman without reconfiguration.

This means: if FilaMan is configured, the scale talks to FilaMan using the Spoolman API. FilaMan then handles synchronisation with Spoolman internally — no duplicate pushes needed.

### Priority Logic

```
Boot
 │
 ├─► filaman_ip configured?
 │    ├─► Yes → probe http://<filaman_ip>/spoolman/api/v1/health
 │    │         ├─► HTTP 200 → use FilaMan as backend ✅
 │    │         └─► Error   → fallback to Spoolman ⚠️
 │    │
 │    └─► No → use Spoolman directly
 │
 └─► Weight push (PATCH /spool/<id>) → active backend
```

### Configuration

Set the IPs in `example_config.yaml`:

```yaml
substitutions:
  spoolman_ip: "192.168.0.1:7912"   # always set this
  filaman_ip:  "192.168.0.1:8083"   # leave empty to skip FilaMan
```

To use **Spoolman only**, leave `filaman_ip` empty:
```yaml
  filaman_ip: ""
```

To use **FilaMan only** (with FilaMan→Spoolman sync handled by FilaMan):
```yaml
  filaman_ip: "192.168.0.1:8083"
  spoolman_ip: ""   # not needed if FilaMan handles Spoolman internally
```

### The sync call (identical for both backends)

```http
PATCH http://<backend>/api/v1/spool/<spool_id>
Content-Type: application/json

{ "remaining_weight": 217.4 }
```

| Backend | Effective URL |
| :--- | :--- |
| FilaMan | `http://<filaman_ip>/spoolman/api/v1/spool/<id>` |
| Spoolman | `http://<spoolman_ip>/api/v1/spool/<id>` |

### HTTP Response Codes

| Code | Meaning | Device reaction |
| :--- | :--- | :--- |
| `200` | Sync successful | ✅ Confirm beep |
| `404` | Spool ID not found | ❌ Error beep, log warning |
| Other | Server error | ❌ Error beep, log warning |

### Manual Sync

```bash
curl -X POST http://192.168.0.50/button/sync/press
```

---

## NFC / RFID Tag Integration

> 🔲 Planned — not yet implemented

When an NFC tag is scanned, the scale reads the spool ID from the tag and automatically pushes the current weight to the active backend (FilaMan or Spoolman).

If no FilaMan is configured and a spool is identified via Spoolman, the Spoolman spool ID can be written back to the NFC tag for future auto-identification.

---
---

# 🔌 API-Dokumentation

Dieses Dokument beschreibt alle externen Schnittstellen der ESPHome Filamentwaage: die native ESPHome REST API, die Home Assistant Integration sowie die einheitliche Sync-Logik für Spoolman und FilaMan.

---

## ESPHome REST API

ESPHome stellt eine eingebaute REST API bereit, über die Sensorwerte ausgelesen und Aktionen ausgelöst werden können – ohne Home Assistant.

**Basis-URL:** `http://<Geräte-IP>/`

### Sensorwerte abfragen

```http
GET /sensor/<sensor_id>
```

| Sensor-ID | Beschreibung |
| :--- | :--- |
| `filament_weight` | Aktuelles Nettogewicht in Gramm |
| `filament_remaining_pct` | Berechnetes Restfilament in % |

**Beispiel:**
```bash
curl http://192.168.0.50/sensor/filament_weight
```
```json
{ "id": "sensor-filament_weight", "value": 217.4, "state": "217.4 g" }
```

### Button-Aktionen

```http
POST /button/<button_id>/press
```

| Button-ID | Beschreibung |
| :--- | :--- |
| `tare_scale` | Waage tarieren (nullen) |
| `sync` | Sync zum aktiven Backend manuell auslösen |

**Beispiel:**
```bash
curl -X POST http://192.168.0.50/button/sync/press
```

---

## Home Assistant Integration

Das Gerät integriert sich nativ über die **ESPHome-Integration** in Home Assistant (API-Schlüssel erforderlich).

### Einrichtung

1. In Home Assistant: **Einstellungen → Geräte & Dienste → Integration hinzufügen → ESPHome**.
2. IP-Adresse des Geräts eingeben.
3. API-Schlüssel aus der `example_config.yaml` eingeben.

### Verfügbare Entitäten

| Entität | Typ | Beschreibung |
| :--- | :--- | :--- |
| `sensor.filament_weight` | Sensor | Aktuelles Nettogewicht (g) |
| `sensor.filament_remaining_pct` | Sensor | Restfilament (%) |
| `button.tare_scale` | Button | Waage tarieren |
| `button.sync` | Button | Sync zum aktiven Backend auslösen |
| `switch.winder_enabled` | Switch | Wickler aktivieren/deaktivieren |
| `number.winder_speed` | Number | Wicklergeschwindigkeit (0–100 %) |

### Beispiel-Automation

```yaml
automation:
  - alias: "Benachrichtigung bei wenig Filament"
    trigger:
      - platform: numeric_state
        entity_id: sensor.filament_remaining_pct
        below: 15
    action:
      - service: notify.mobile_app
        data:
          message: "⚠️ Filament unter 15 % – bitte Spule wechseln!"
```

---

## Sync-Logik — FilaMan & Spoolman

Die Waage verwendet einen **einheitlichen Sync-Mechanismus** (`sync.yaml`), der beim Start automatisch das richtige Backend erkennt. Sowohl FilaMan als auch Spoolman verwenden dieselbe Spoolman-kompatible REST API — der HTTP-Aufruf ist identisch, nur die Basis-URL unterscheidet sich.

### Wie FilaMan und Spoolman zusammenhängen

FilaMan bietet ein **Spoolman API Plugin**, das eine vollständig Spoolman-kompatible REST API unter `/spoolman/api/v1/` bereitstellt. Externe Tools können FilaMan damit als direkten Ersatz für Spoolman verwenden. Ist FilaMan konfiguriert, spricht die Waage über die Spoolman-API mit FilaMan — FilaMan übernimmt die interne Synchronisierung mit Spoolman. Kein doppelter Push nötig.

### Priorisierungslogik

```
Start
 │
 ├─► filaman_ip konfiguriert?
 │    ├─► Ja → http://<filaman_ip>/spoolman/api/v1/health prüfen
 │    │         ├─► HTTP 200 → FilaMan als Backend verwenden ✅
 │    │         └─► Fehler   → Fallback auf Spoolman ⚠️
 │    │
 │    └─► Nein → Spoolman direkt verwenden
 │
 └─► Gewicht-Push (PATCH /spool/<id>) → aktives Backend
```

### Konfiguration

IPs in der `example_config.yaml` eintragen:

```yaml
substitutions:
  spoolman_ip: "192.168.0.1:7912"   # immer angeben
  filaman_ip:  "192.168.0.1:8083"   # leer lassen um FilaMan zu überspringen
```

**Nur Spoolman** — `filaman_ip` leer lassen:
```yaml
  filaman_ip: ""
```

**Nur FilaMan** (FilaMan → Spoolman Sync läuft intern über FilaMan):
```yaml
  filaman_ip: "192.168.0.1:8083"
  spoolman_ip: ""
```

### Der Sync-Aufruf (identisch für beide Backends)

```http
PATCH http://<backend>/api/v1/spool/<spool_id>
Content-Type: application/json

{ "remaining_weight": 217.4 }
```

| Backend | Effektive URL |
| :--- | :--- |
| FilaMan | `http://<filaman_ip>/spoolman/api/v1/spool/<id>` |
| Spoolman | `http://<spoolman_ip>/api/v1/spool/<id>` |

### HTTP-Antwortcodes

| Code | Bedeutung | Reaktion des Geräts |
| :--- | :--- | :--- |
| `200` | Sync erfolgreich | ✅ Bestätigungs-Beep |
| `404` | Spulen-ID nicht gefunden | ❌ Fehler-Beep, Log-Warnung |
| Sonstige | Serverfehler | ❌ Fehler-Beep, Log-Warnung |

### Manueller Sync

```bash
curl -X POST http://192.168.0.50/button/sync/press
```

---

## NFC / RFID Tag Integration

> 🔲 Geplant — noch nicht implementiert

Wird ein NFC-Tag gescannt, liest die Waage die Spulen-ID vom Tag und überträgt das aktuelle Gewicht automatisch an das aktive Backend (FilaMan oder Spoolman).

Ist kein FilaMan konfiguriert und eine Spule über Spoolman identifiziert, kann die Spoolman-Spulen-ID zur künftigen automatischen Erkennung auf den NFC-Tag zurückgeschrieben werden.

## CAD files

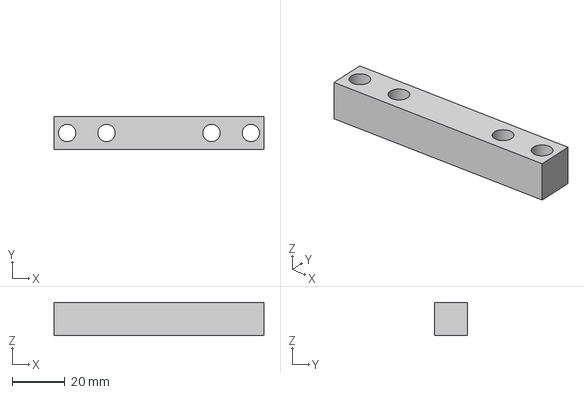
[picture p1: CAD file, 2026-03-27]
tools/LoadCell_80x12.7_Reference_Model.3mf
80.0 x 12.7 x 12.7 mm

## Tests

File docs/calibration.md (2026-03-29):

# ⚖ Calibration Guide

> 🇩🇪 [Deutsche Version weiter unten](#-kalibrierungsanleitung)

---

This guide explains how to calibrate the load cell so the scale reads accurate weights.

Calibration is done entirely via **Home Assistant** — no reflash or YAML editing required. All values are stored directly on the device and survive reboots.

---

## Prerequisites

- The scale is flashed and connected to your network.
- The device has been adopted in your ESPHome dashboard or Home Assistant.
- You have a known reference weight (e.g. a 1 kg spool, a calibration weight, or any object with a known mass).
- The scale platform is empty and stable.

---

## Step 1 – Tare (Zero the Scale)

1. Remove everything from the scale platform.
2. In Home Assistant, go to your **Filament Scale device** → **Controls**.
3. Press the **"Tare Scale"** button.

The `Weight` sensor should now show `0.0 g`.

---

## Step 2 – Read the Raw Value

1. Place your known reference weight on the platform (e.g. exactly **1000 g**).
2. In Home Assistant, go to your **Filament Scale device** → **Sensors**.
3. Note the current value of **"Scale Raw"** — e.g. `412380`.

> ℹ️ The `Scale Raw` sensor shows the unprocessed integer value from the HX711. It is visible as a diagnostic entity in Home Assistant.

---

## Step 3 – Calculate the Calibration Factor

```
Calibration Factor = Raw Value / Known Weight in grams
Calibration Factor = 412380 / 1000 = 412.38
```

---

## Step 4 – Enter the Calibration Factor

1. In Home Assistant, go to your **Filament Scale device** → **Controls**.
2. Find the **"Calibration Factor"** number entity.
3. Enter your calculated value (e.g. `412.38`).

The `Weight` sensor updates immediately — no reflash needed. ✅

---

## Step 5 – Set Spool Weights (Optional)

For accurate **Filament Remaining %** calculation, set your spool weights:

| Entity | Description | Typical Value |
| :--- | :--- | :--- |
| **Empty Spool Weight** | Weight of the empty spool (no filament) | 200 g |
| **Total Filament Weight** | Total filament weight when full | 1000 g |

These are also number entities in Home Assistant and stored on the device.

---

## Step 6 – Verify Accuracy

1. Tare the scale (empty platform).
2. Place the reference weight on the platform.
3. The `Weight` sensor should now show the correct weight ± 1–2 g.
4. For higher accuracy, use multiple reference weights and average the factor.

---

## Tips & Troubleshooting

| Issue | Possible Cause | Solution |
| :--- | :--- | :--- |
| Value drifts over time | Temperature changes | Re-tare after warm-up (~5 min) |
| Reading is off by a fixed offset | Tare not performed | Tare with empty platform |
| Reading is off by a percentage | Wrong calibration factor | Recalculate and update factor |
| Unstable / noisy reading | Mechanical vibration | Ensure stable surface, check cell mounting |
| Value jumps to max | Wiring issue | Check DT/SCK pin connections |
| `Scale Raw` shows `NaN` | HX711 not connected | Check DT/SCK wiring |

---
---

# ⚖ Kalibrierungsanleitung

Die Kalibrierung erfolgt vollständig über **Home Assistant** — kein erneutes Flashen oder Bearbeiten von YAML-Dateien erforderlich. Alle Werte werden direkt auf dem Gerät gespeichert und bleiben auch nach einem Neustart erhalten.

---

## Voraussetzungen

- Die Waage ist geflasht und mit dem Netzwerk verbunden.
- Das Gerät wurde im ESPHome-Dashboard oder in Home Assistant adoptiert.
- Ein bekanntes Referenzgewicht liegt bereit (z. B. eine 1-kg-Spule, ein Kalibriergewicht oder ein Objekt mit bekannter Masse).
- Die Wägeplattform ist leer und stabil.

---

## Schritt 1 – Tarieren (Nullen der Waage)

1. Alles von der Wägeplattform entfernen.
2. In Home Assistant zum **Filament Scale Gerät** → **Steuerelemente** navigieren.
3. Den Button **"Tare Scale"** drücken.

Der Sensor `Weight` zeigt nun `0.0 g`.

---

## Schritt 2 – Rohwert ablesen

1. Referenzgewicht auf die Plattform legen (z. B. genau **1000 g**).
2. In Home Assistant zum **Filament Scale Gerät** → **Sensoren** navigieren.
3. Den aktuellen Wert von **"Scale Raw"** notieren — z. B. `412380`.

> ℹ️ Der Sensor `Scale Raw` zeigt den unverarbeiteten Integer-Wert des HX711. Er ist als Diagnose-Entität in Home Assistant sichtbar.

---

## Schritt 3 – Kalibrierungsfaktor berechnen

```
Kalibrierungsfaktor = Rohwert / bekanntes Gewicht in Gramm
Kalibrierungsfaktor = 412380 / 1000 = 412.38
```

---

## Schritt 4 – Kalibrierungsfaktor eintragen

1. In Home Assistant zum **Filament Scale Gerät** → **Steuerelemente** navigieren.
2. Die Number-Entität **"Calibration Factor"** suchen.
3. Den berechneten Wert eintragen (z. B. `412.38`).

Der Sensor `Weight` aktualisiert sich sofort — kein erneutes Flashen nötig. ✅

---

## Schritt 5 – Spulengewichte festlegen (Optional)

Für eine genaue **Restfilament-%**-Berechnung die Spulengewichte eintragen:

| Entität | Beschreibung | Typischer Wert |
| :--- | :--- | :--- |
| **Empty Spool Weight** | Gewicht der leeren Spule (ohne Filament) | 200 g |
| **Total Filament Weight** | Gesamtfilamentgewicht bei voller Spule | 1000 g |

Diese sind ebenfalls Number-Entitäten in Home Assistant und werden auf dem Gerät gespeichert.

---

## Schritt 6 – Genauigkeit überprüfen

1. Waage erneut tarieren (leere Plattform).
2. Referenzgewicht auf die Plattform legen.
3. Der Sensor `Weight` sollte nun das korrekte Gewicht ± 1–2 g anzeigen.
4. Für höhere Genauigkeit mehrere Referenzgewichte verwenden und den Faktor mitteln.

---

## Tipps & Fehlerbehebung

| Problem | Mögliche Ursache | Lösung |
| :--- | :--- | :--- |
| Wert driftet über die Zeit | Temperaturschwankungen | Nach Aufwärmzeit (~5 min) neu tarieren |
| Wert um festen Offset falsch | Tarierung nicht durchgeführt | Mit leerer Plattform tarieren |
| Wert prozentuell falsch | Falscher Kalibrierungsfaktor | Faktor neu berechnen und eintragen |
| Instabiler / verrauschter Wert | Mechanische Vibrationen | Stabilen Untergrund sicherstellen, Zellenhalterung prüfen |
| Wert springt auf Maximum | Verkabelungsfehler | DT/SCK-Pinverbindungen prüfen |
| `Scale Raw` zeigt `NaN` | HX711 nicht verbunden | DT/SCK-Verkabelung prüfen |

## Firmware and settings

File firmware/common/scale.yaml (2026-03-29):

# ============================================================
# scale.yaml
# HX711 load cell: raw reading, calibration, tare, filters
#
# Calibration factor can be set two ways:
#   Option 1 — via substitution in main.yaml (default/initial value)
#   Option 2 — via "Calibration Factor" number entity in Home Assistant
#              (stored on device, survives reboots)
#
# Calibration procedure:
#   1. Empty platform → press "Tare Scale"
#   2. Place known weight (e.g. 1000g)
#   3. Read "Scale Raw" value from HA diagnostic sensor
#   4. Calculate: factor = raw_value / known_weight_in_grams
#   5. Enter factor in "Calibration Factor" number entity in HA
# ============================================================

esphome:
  on_boot:
    priority: -50
    then:
      # If substitution set → override HA entity (Power User)
      # If substitution empty → keep HA entity value (Normal User)
      - lambda: |-
          std::string sub = "${scale_calibration_factor}";
          if (!sub.empty()) {
            float val = atof(sub.c_str());
            if (val > 0) {
              auto call = id(calibration_factor).make_call();
              call.set_value(val);
              call.perform();
              ESP_LOGI("scale", "Calibration factor from substitution: %.1f", val);
            }
          }

globals:
  - id: scale_tare_offset
    type: float
    restore_value: true
    initial_value: "0.0"

  - id: spool_empty_weight
    type: float
    restore_value: true
    initial_value: "200.0"

  - id: spool_total_filament
    type: float
    restore_value: true
    initial_value: "1000.0"

number:
  # -- Calibration factor --
  # Initial value comes from substitution (main.yaml or example_config.yaml)
  # Can be overridden at runtime via Home Assistant UI
  - platform: template
    id: calibration_factor
    name: "Calibration Factor"
    icon: mdi:tune
    entity_category: config
    min_value: 1
    max_value: 100000
    step: 0.1
    restore_value: true
    initial_value: 420.0
    optimistic: true
    on_value:
      then:
        - logger.log:
            format: "Calibration factor updated: %.1f"
            args: ["x"]

  # -- Empty spool weight --
  - platform: template
    id: num_spool_empty_weight
    name: "Empty Spool Weight"
    icon: mdi:weight-gram
    unit_of_measurement: "g"
    entity_category: config
    min_value: 0
    max_value: 1000
    step: 1
    restore_value: true
    initial_value: 200
    optimistic: true
    on_value:
      then:
        - globals.set:
            id: spool_empty_weight
            value: !lambda "return x;"

  # -- Total filament weight --
  - platform: template
    id: num_spool_total_filament
    name: "Total Filament Weight"
    icon: mdi:weight-gram
    unit_of_measurement: "g"
    entity_category: config
    min_value: 0
    max_value: 5000
    step: 1
    restore_value: true
    initial_value: 1000
    optimistic: true
    on_value:
      then:
        - globals.set:
            id: spool_total_filament
            value: !lambda "return x;"

sensor:
  # -- Raw HX711 value (visible for calibration) --
  - platform: hx711
    id: scale_raw
    name: "Scale Raw"
    internal: false
    icon: mdi:numeric
    entity_category: diagnostic
    dout_pin: ${pin_scale_dt}
    clk_pin: ${pin_scale_sck}
    gain: 128
    update_interval: 500ms
    filters:
      - sliding_window_moving_average:
          window_size: 5
          send_every: 1

  # -- Calibrated weight in grams --
  - platform: template
    id: scale_weight
    name: "Weight"
    unit_of_measurement: "g"
    accuracy_decimals: 1
    icon: mdi:scale-balance
    device_class: weight
    state_class: measurement
    update_interval: 500ms
    lambda: |-
      float raw = id(scale_raw).state;
      float tare = id(scale_tare_offset);
      float factor = id(calibration_factor).state;
      if (factor <= 0) return 0.0f;
      float weight = (raw - tare) / factor;
      if (weight < 0.5f && weight > -5.0f) weight = 0.0f;
      return weight;
    filters:
      - delta: 0.5

  # -- Filament remaining in % --
  - platform: template
    id: filament_remaining_pct
    name: "Filament Remaining"
    unit_of_measurement: "%"
    accuracy_decimals: 0
    icon: mdi:percent
    state_class: measurement
    update_interval: 5s
    lambda: |-
      float net = id(scale_weight).state;
      float spool = id(spool_empty_weight);
      float total = id(spool_total_filament);
      if (total <= 0) return NAN;
      float remaining = ((net - spool) / total) * 100.0f;
      return clamp(remaining, 0.0f, 100.0f);
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

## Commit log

2026-03-27 adding reference model for the load cell
    [LoadCell_80x12.7_Universal_Reference_Model.3mf]
2026-03-27 move load cell reference file to tools
    [LoadCell_80x12.7_Reference_Model.3mf]
2026-03-27 Update manifest for Filament Scale versioning and path
2026-03-27 enable stepper and winder config in example_conf and changed checks in validation job
2026-03-27 removed current versions of spoolman and filaman scripts from config.
2026-03-27 Update hardware documentation for power supply
2026-03-27 Development (#18)
    * add sensors and change order of includes
    * combine filaman and spoolman sync into one file; update api documentation
    * smaller fixes and cleanup
    * with scripts (will probably return errors)
    * remove scripts again
    * fixed remaining, empty "on_boot" command
    * fixed sync btn name
    * fix multiple usage of addon sensor
2026-03-27 Development (#19)
    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
2026-03-28 fix esp32 and esphome nodes
2026-03-28 fix framework information
2026-03-28 fixed missing prefix for device name and such
2026-03-28 fixed missing device_name
2026-03-28 updated calibration docu
2026-03-28 uncommented stepper config due to validation error in controls and display.
2026-03-29 Remove emoji variation from calibration guide headers
2026-03-29 updated stepper motor schema for generic driver
2026-03-29 rename entities and remove leading device_name
